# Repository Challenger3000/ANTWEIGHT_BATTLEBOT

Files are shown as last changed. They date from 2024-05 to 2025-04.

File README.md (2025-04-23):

"# ANTWEIGHT_ESP_BATTLEBOT" 

This is an example code that is meant to run an ESP32S3 battlebot / remote 

The main brain of the robot has the following hardware
1. ESP32S3
2. DRV8908 brushed motor driver IC
3. 3.3v regulator
4. 5.0v regulator
5. LSM6DSLTR Gyro/accelerometer
6. RGB LED
7. 1-4s battery charger

Transmitter hardware consists of 
1. ESP32S3
3. 3.3v regulator
5. LSM6DSLTR Gyro/accelerometer
6. 4x individually addressable RGB LEDs
7. 1-4s battery charger

The main features of this code ...
1. Conveneinent binding between robot and transmitter
2. Simple interface with the motor driver
3. 2x servo outputs on pins IO37 and IO38
4. PID control loop for yaw rate control
5. Website hosting over wifi for PID/Configuration setting changes.
6. Robot battery telemetry ais ccessible on the remote.

**Code uploading...**
1. install Arduino IDE 2.3.2 from https://www.arduino.cc/en/software
2. add "Arduino ESP32 Boards By Arduino" and "esp32 by Espressif v2.0.16" following this tutorial:
https://randomnerdtutorials.com/installing-the-esp32-board-in-arduino-ide-windows-instructions/

IMPORTANT!!!

To successfully compile code, make sure Esp32 library version is: 2.0.16

Otherwise the code does not compile.

image description

4. Try to compile, flash/verify, and install all libraries.
   * AsyncTCP
   * ESPAsyncWebServer
   * FastLED
   * FastIMU
   * 1euroFilter
   * PID
   * ESP32Servo   
5. Connect robot, select com port and chose ESP32S3 Dev
6. Set these parameters in arduino ide:

image description

7. Upload code....
If you encounter exit status 1 or status 2, or the IDE claims the controller does not respond...
This means that the BootLoader has been corrupted. Usually caused by flashing Firmware with ERASER ALL FLASH enabled.
To fix this...
1. Hold down PROGRAM button found on the back side of the main board while powering on.
2. Select Esptool as the programmer in the tools dropdown menu,
3. Click BurnBootloader button within tools doropdown menu (takes about 15-20s to complete)
4. After you see "Hard reset" message in the console, upload the code again.
After upload perform a reboot, and you should be able to upload the code without heaving to press the PROGRAM button every time

**Binding process...**

1. Hold down "B" button on transmitter and turn it on, once you see the second rgb led from the left side blinking blue and cyan.
2. Hold top side button on the robot while turning the robot on until you see rgb led blinking blue and cyan.
3. Keep the robots withing 2m or so, it should take around 5 seconds to bind.
   
**Motor driver...**

The motor driver onboard has 4 full bridges. So its capable of driving 4 1.0 - 1.5 A motors, or 2 2.0 - 3.0 A motors
You have to chose the descired configuration in configuration.h by setting 
MOTOR_LAYOUT = PARALEL_AC_BD or INDIVIDUAL_A_B_C_D
After initializing the motor driver, you can simply use drive_motor_A() and motor A will drive.
If you're using 2 parallel motors and not 4 individual motors, motor A C, and B D, will work together to achieve more current.
For more detailed information for the motor driver, you can check out the datasheet: 
https://www.ti.com/lit/ds/symlink/drv8912-q1.pdf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
The motor driver has OVER CURRENT PROTECTION, if robot detects the over current protection it will flash onboard status led YELOW.

**PID control...**

The robot and remote has a built-in imu in both robot and transmitter. Currently not supported on transmitters side. IMU used is LSM6DSLTR, SDA is connected to io48 and SCL to io47, in case you want to add support.
By default, robot comes with, 3 modes on 2nd switch. Off on the bottom, On no IMU in the middle, On with imu stabilisation pointing forwards.
When in imu stabilisation mode, robot will track rotational speed.
For example if the sitck is in the middle, the robot will try to stay motionless, it will resist pushes and hit better.
If you rotate your stick as far to the left as you can, it will by default try to maintain 600 deg/s. This can be changed in configuration.h.

**Website hosting over wifi...**

For imu PIDs to work you need to tune them. the easiest way to do that is by using wifi website mode. 
To aces this website press the general purpose button while the robot is on, led will change to purple and control will be lost.
Then you can connect to wifi, by default its called PID_SETUP_WIFI with pasword 12345678 . PLEASE CHANGE THIS TO YOUR OWN WIFI NAME AND PASS.
Then connect to wifi and open this: 192.168.4.1 IP address in a browser. You will be greated with a website asking for P I and D parameters
After your done changing pids, you click send, if the robot receives the changes, it will flash white once. then you can click the button again to go back to driving mode.
The website being hosted can be changed, in wifi.ino file.

**Robot led status explanations...**

Red - not connected,
Red blinking - Calibrating IMU
Green - connected, 
Yellow - motor driver over current

Robot board consists of main brain with the driver, and imu. and an addon charger board. 
REMEBER TO SHORT THE CORRECT SOLDER BRIDGE CORSPONDING TO YOUR BATTERY!
(Default is 3s)

image description
image description
image description
image description

**Transmitter has 4 addressable LEDs...**

* 1st LED ... green - yellow - red - red blinking - black.... the color state represents the charge state of the remote.
* 2nd LED ...
  * green - yellow - red - red blinking - black.... all of them represent the charge state of the robot. (only if telemetry from robot is present)
  * Blue/cyan blinking - binding mod.
* 3rd LED joystick X-axis calibration indicator
* 4rd LED joystick Y-axis calibration indicator

**Transmitter joystick calibration**
3rd and 4th LEDs help identify a bad joystick calibration.
Both LEDs represent joystick data after applying limit and midpoint calibration.
3rd LED - x-axis, 4th LED - y axis.
  * green - axis centered,
  * yellow - axis is moved off center,
  * red - axis at the limit of travel.

If you dont see a green indicator on 3rd and 4th LED while stick is in the middle,
this means that the stick is not calibrated correctly.
To calibrate the youstick,
  1. Pull the stick to the left bottom corner while powering on the remote.
  2. Release the stick once you see RED - GREEN blinking indicators on ALL LEDs.
     (while the LEDs indicate a solid RED color, its calibrating the midpoint of the joystick, so do not move it)
  3. When all 4 leds indicate a YELLOW light, move the stick around to all corners and edges.
     (this stage lasts for 10s, I usually just rotate it clockwise and counterclockwise for 3 times each.)
  4. When you see a green light, the calibration is finishes and parameters saved.

**Keep in mind!**

Esp32 s3 doesn't like Printing in serial while no serial connection is present, so comment out all serial print or use switches on the transmitter to enable/disable serial prints on the robot/transmitter.
If you do a lot of printing, with no serial cable attached, ESP will start to lag

While connecting the usb extension board, make sure d+ and d- are connected accordingly.

**Hardware revision changelog**
Revision v2.0 remote VS v2.1:

image description

Diffrence: A/B push buttons swapped, NEW more durrable power switch.

Revision v2.0 brain board VS v2.1:

image description

Diffrence: Added extra VSENSE pin for higher voltage weapon battery (drive batery VSENSE moved to pin 9 from 10. New extra VSENSE pin 10)

**TODO**
1. Need to organize and clean transmitter code.
2. Update the code to work with the newer version of ESP32 and FastLED librarys...
3. Switch to a newer/better/from scratch IMU/PID library, cause the current ones stop working after "micros()" overflows.
4. Add support for brushels esc drive.

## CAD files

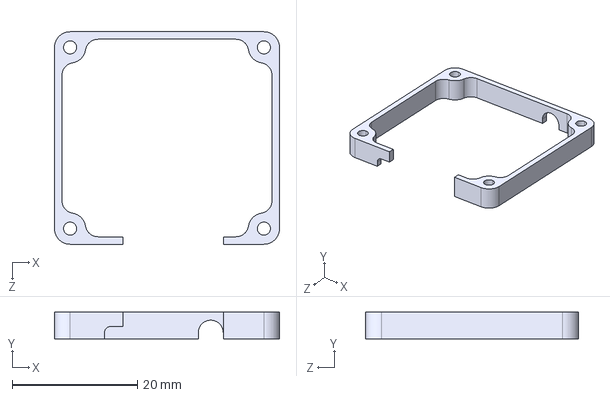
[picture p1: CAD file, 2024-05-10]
3D_files/BrainSpacer.STEP
36.0 x 4.30 x 34.0 mm

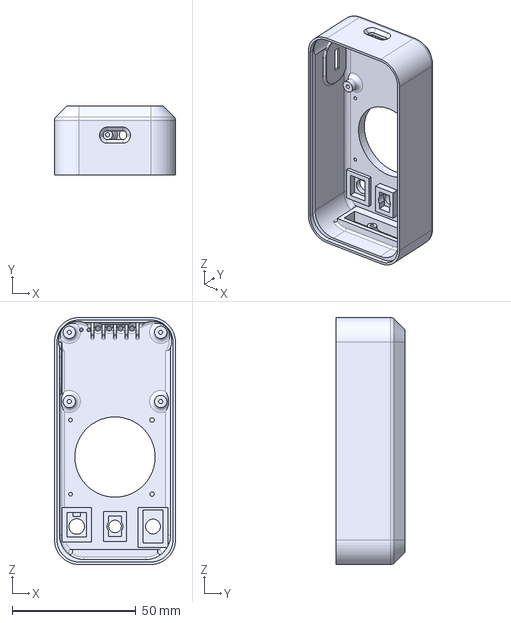
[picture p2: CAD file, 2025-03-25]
3D_files/NuleTX REV 2/NULE TX v3.3.step
49.0 x 28.0 x 100.0 mm

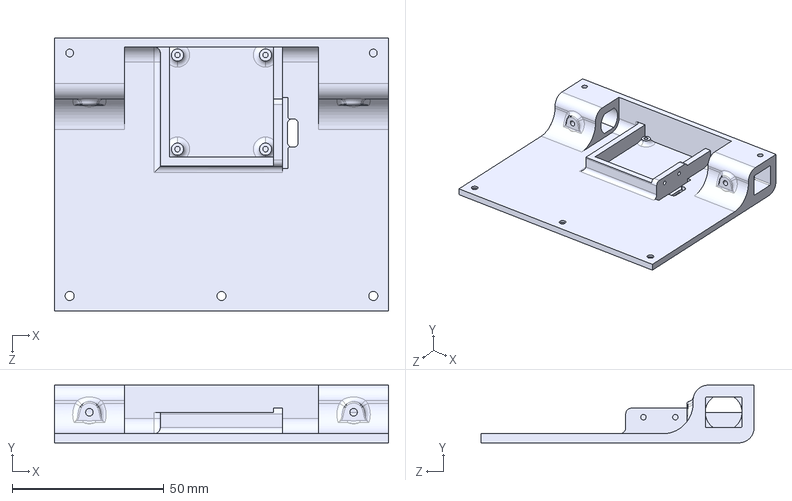
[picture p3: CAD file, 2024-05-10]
3D_files/BasicDriveNule.STEP
110.0 x 19.0 x 90.0 mm

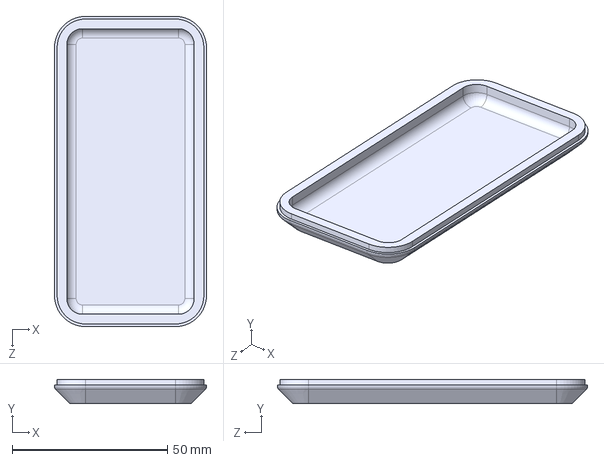
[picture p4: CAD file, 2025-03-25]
3D_files/NuleTX REV 2/NULE TX LID.step
49.0 x 7.80 x 100.0 mm

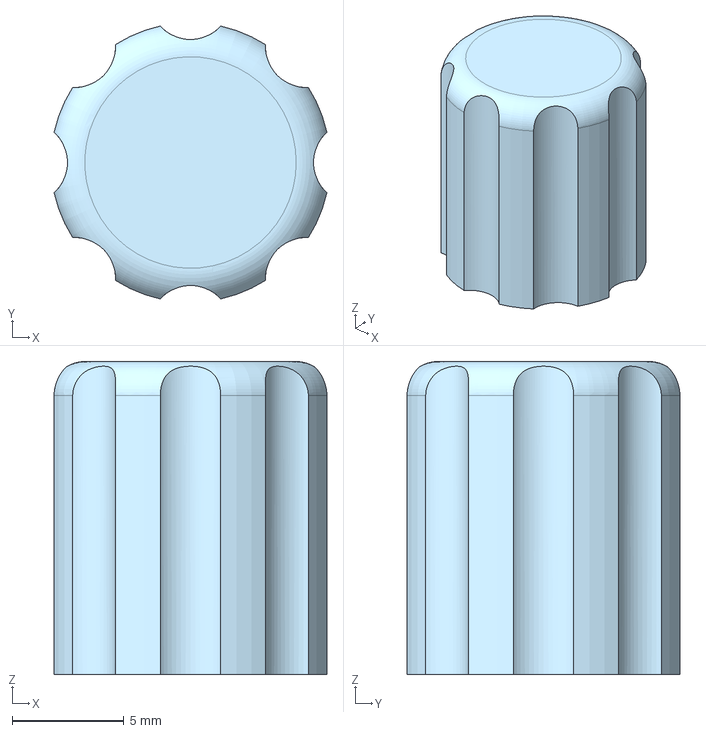
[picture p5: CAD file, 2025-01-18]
3D_files/NuleTX REV 2/Knob.step
12.2 x 12.2 x 14.0 mm

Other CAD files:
3D_files/NuleTX REV 1/NuleTXLid.STEP
3D_files/NuleTX REV 1/NuleTX_v1.0.STEP
3D_files/NuleTX REV 1/NuleTX_v1.1.step

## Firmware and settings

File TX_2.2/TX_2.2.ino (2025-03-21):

// general
enum TX_STATES {
  IDLE,
  SENDING,
  BINDING,
};
uint8_t state = SENDING;
bool new_rx_data = false;

// eeprom code start
#define EEPROM_SIZE 200
#define EEPROM_ADDRES 100
#include <EEPROM.h>

typedef struct struct_eeprom {
  uint8_t   eeprom_structure_version;
  uint8_t   reserved;
  uint8_t   need_to_calibrate;
  int32_t   calib_x_low;
  int32_t   calib_x_high;
  int32_t   calib_y_low;
  int32_t   calib_y_high;
  int32_t   offset_x;
  int32_t   offset_y;
  uint8_t   binding_status;
  uint8_t   bound_ch;
  uint8_t   bound_mac[6];
  char      encryption_key[16];
} struct_eeprom;
struct_eeprom EEPROM_DATA;

void init_eeprom(){  
  EEPROM.begin(EEPROM_SIZE);
  EEPROM.get(EEPROM_ADDRES, EEPROM_DATA);
}
// eeprom code end

// esp now code start
#include "esp_wifi.h"
#include <esp_now.h>
#include <WiFi.h>
void OnDataSent(const uint8_t *mac_addr, esp_now_send_status_t status);
#define rssi_list_size 50
#define binding_ch 14
uint8_t current_ch = 0;
uint8_t sending_ch = 5;
uint8_t broadcastAddress[] = {0xFF, 0xFF, 0xFF, 0xFF, 0xFF, 0xFF};
char pmk_key_str[16];
uint16_t failed_packet_count = 0;
bool rx_lost = true;

struct rssi_data {
  uint8_t mac_address[6];
  int rssi;
  uint8_t received_packets;
};
rssi_data rssi_list[rssi_list_size] = {0};
rssi_data rssi_receive_buffer[rssi_list_size] = {0};
uint8_t rssi_list_index = 0;
uint8_t rssi_receive_buffer_index = 0;
uint8_t strongest_rssi_index = 0;

unsigned long last_strongest_receive = 0;
unsigned long last_sendtime = 0;
unsigned long last_receive=0;
esp_now_peer_info_t peerInfo;
// esp now code end

// hardware pins
#define g_x 4
#define g_y 5
#define pot 6
#define switch_1      14
#define switch_2_up   12
#define switch_2_down 11
#define switch_3      13
#define vbat 8

// rev 2.0
// #define BTN_A 9
// #define BTN_B 21

// rev 2.1
#define BTN_A 21
#define BTN_B 9

// variables
typedef struct struct_message_rx {
  float     volatage;
} struct_message_rx;
struct_message_rx rxData;

typedef struct struct_message_tx {
  uint8_t   mode;
  uint8_t   id;
  int32_t   x_axis;
  int32_t   y_axis;
  uint32_t  pot_1;
  uint8_t   sw_1;
  uint8_t   sw_2;
  uint8_t   sw_3;
  uint8_t   btn_A;
  uint8_t   btn_B;
  uint8_t   ch09;
  uint8_t   ch10;
  uint8_t   ch11;
  uint8_t   ch12;
  uint8_t   ch13;
  uint8_t   ch14;
  uint8_t   ch15;
  uint8_t   ch16;
  char string[16];
  uint8_t mac[6];
} struct_message_tx;
struct_message_tx txData;
int ch1_offset = 0;
int ch2_offset = 0;
int motorA = 0;
int motorB = 0;
uint8_t expo_B = 0;


// led code start
#include <FastLED.h>
#define NUM_LEDS 4
#define DATA_PIN 1
CRGB leds[NUM_LEDS];
unsigned long last_led_update = 0;
bool led_warning_phase = false;
// led code end

// rssi
typedef struct {
  unsigned frame_ctrl: 16;
  unsigned duration_id: 16;
  uint8_t addr1[6]; /* receiver address */
  uint8_t addr2[6]; /* sender address */
  uint8_t addr3[6]; /* filtering address */
  unsigned sequence_ctrl: 16;
  uint8_t addr4[6]; /* optional */
} wifi_ieee80211_mac_hdr_t;

typedef struct {
  wifi_ieee80211_mac_hdr_t hdr;
  uint8_t payload[0]; /* network data ended with 4 bytes csum (CRC32) */
} wifi_ieee80211_packet_t;

int rssi_last;
unsigned long last_list_print = 0;

void setup() {
  // Serial.begin(115200);
  init_led();
  init_eeprom();
  init_gpio();

  if (get_button_B()) {
    state = BINDING;
  } else {
    if (EEPROM_DATA.binding_status == 1) {
      state = SENDING;
    } else {
      state = BINDING;
    }
  }

  init_data_structures();
  init_esp_now();
  init_joystick();
}

void loop() {
  if(millis()-last_led_update > 25){
    last_led_update = millis();
    update_leds();

    // print all hardware pin values
    
    // Serial.print("x: ");
    // Serial.print(mapWithMidpoint(constrain(analogRead(g_x),EEPROM_DATA.calib_x_low ,EEPROM_DATA.calib_x_high), EEPROM_DATA.calib_x_low, ch1_offset, EEPROM_DATA.calib_x_high, 0, 4095));
    // Serial.print("\ty: ");
    // Serial.print(mapWithMidpoint(constrain(analogRead(g_y),EEPROM_DATA.calib_y_low,EEPROM_DATA.calib_y_high), EEPROM_DATA.calib_y_low, ch2_offset, EEPROM_DATA.calib_y_high, 0, 4095));
    // Serial.print("g_x: ");
    // Serial.print(analogRead(g_x));
    // Serial.print("\tg_y: ");
    // Serial.print(analogRead(g_y));
    // Serial.print("\tpot: ");
    // Serial.print(analogRead(pot));
    // Serial.print("\tsw1: ");
    // Serial.print(get_switch_1());
    // Serial.print("\tsw2: ");
    // Serial.print(get_switch_2());
    // Serial.print("\tsw3: ");
    // Serial.print(get_switch_3());
    // Serial.print("\tBTN_A: ");
    // Serial.print(get_button_A());
    // Serial.print("\tBTN_B: ");
    // Serial.println(get_button_B());
  }

  switch (state) {
    case SENDING:

      if(!rx_lost && millis()-last_sendtime > 50){
        last_sendtime = millis();
        send_data();
      }else if(rx_lost && millis()-last_sendtime > 1000){
        last_sendtime = millis();
        send_data();
      }
      break;

    case BINDING:      
      binding();
      break;
  }
}

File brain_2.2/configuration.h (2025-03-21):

// Drive motor related settings
bool motors_on = true;                      // turns on and off all motors in one boolean. 
#define max_throttle 255                    // max throttle value  
// INDIVIDUAL_A_B_C_D - for 1x4 individual motors.
// PARALEL_AC_BD      - for 2x2 motors with A C outputs and B D outputs being paralel.
uint8_t MOTOR_LAYOUT = PARALEL_AC_BD;       // selects motor layout betwheen 2 paralel, and 4 individual
float battery_critical_v = 3.0;
#define cell_count 2.0;

// servo
int servo_1_init_position = 0;              // initial servo position
int servo_2_init_position = 0;              // initial servo position

int servo_1_failsave_position = 0;          // initial servo position
int servo_2_failsave_position = 0;          // initial servo position

bool arming_throttle_protection = true;     // prevents esc from spinning if armed with above 0 throttle

// Wifi related settings
const char* ssid = "PID_SETUP_WIFI";
const char* password = "12345678";

// imu settings
bool use_imu_for_yaw_rate = true;           // if true, yaw rate will be adjusted from imu yaw rate
#define max_yaw_rate 600                    // max yaw rate in degrees per second

// failsave
unsigned int failsave_delay = 500;          // ms until failsave is activated.
#define WDT_TIMEOUT 1                       // watchdog timeout (1s)

// hardware pins
#define SERVO_1_PIN 38
#define SERVO_2_PIN 37
#define BUTTON 4

// rev 2.0
// #define VSENSE 10

// rev v2.1
#define VSENSE 9
// #define VSENSE 10 // changed on rev_2.1 brain boards. can be used to detect voltage of extra external battery

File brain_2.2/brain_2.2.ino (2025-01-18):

#include "variables.h"
#include "configuration.h"

#include <esp_task_wdt.h>

void setup() {
  // Serial.begin(115200);
  init_gpio();
  init_eeprom();
  init_led();
  init_esp_now_rx();
  init_pid();
  init_servo();
  init_imu();
  init_filter();
  init_drv8908(MOTOR_LAYOUT);
  init_watchdog();
}

void loop() {
  led_update();                   // updates the led color based current status
  update_gpio();                  // reads the button and sends the voltage telemetry
  update_filter();                // filters imu data
  update_pid();                   // calculates the PID output
  driving_logic();                // mixes received data and sends it to the motor driver
}

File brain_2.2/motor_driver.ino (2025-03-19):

uint8_t write_register_drv8908(uint8_t write_register, uint8_t write_data){
  digitalWrite(CHIP_SEL, LOW);
  SPI.beginTransaction(SPISettings(1000000, MSBFIRST, SPI_MODE1));
  delayMicroseconds(1);
  drv8908_status = SPI.transfer(write_register);
  uint8_t received_data = SPI.transfer(write_data);
  SPI.endTransaction();
  delayMicroseconds(1);
  digitalWrite(CHIP_SEL, HIGH);
  delayMicroseconds(1);
  // delay(1);
  return received_data;
}

uint8_t read_register_drv8908(uint8_t read_register){
  digitalWrite(CHIP_SEL, LOW);
  SPI.beginTransaction(SPISettings(1000000, MSBFIRST, SPI_MODE1));
  delayMicroseconds(1);
  drv8908_status = SPI.transfer(0b01000000 | read_register);
  uint8_t received_data = SPI.transfer(0x00);
  SPI.endTransaction();
  delayMicroseconds(1);  
  digitalWrite(CHIP_SEL, HIGH);
  delayMicroseconds(1);
  // delay(1);
  return received_data;
}

uint8_t prepare_motor_register(uint8_t motor, uint8_t register){
  uint8_t motor_register = 0;

  return motor_register;
}

void drive_motor_A(uint8_t new_state, uint8_t PWM){
  switch (MOTOR_LAYOUT) {
    case PARALEL_AC_BD:
      switch (new_state) {
        case FORWARD:
          MOTOR_A1_STATE = A1_FORWARD;
          MOTOR_A2_STATE = A2_FORWARD;
          MOTOR_C1_STATE = C1_FORWARD;
          MOTOR_C2_STATE = C2_FORWARD;
          break;
        case BACKWARD:
          MOTOR_A1_STATE = A1_BACKWARD;
          MOTOR_A2_STATE = A2_BACKWARD;
          MOTOR_C1_STATE = C1_BACKWARD;
          MOTOR_C2_STATE = C2_BACKWARD;
          break;
        case COAST: 
          MOTOR_A1_STATE = A1_COAST;
          MOTOR_A2_STATE = A2_COAST;
          MOTOR_C1_STATE = C1_COAST;
          MOTOR_C2_STATE = C2_COAST;
          break;
        case BREAK:
          MOTOR_A1_STATE = A1_BREAK;
          MOTOR_A2_STATE = A2_BREAK;
          MOTOR_C1_STATE = C1_BREAK;
          MOTOR_C2_STATE = C2_BREAK;
          break;
      }
            
      // write_register_drv8908(PWM_CTRL_2, 0xFF);  // disable pwm generation
      write_register_drv8908(PWM_DUTY_1, 0);
      write_register_drv8908(OP_CTRL_1, MOTOR_A1_STATE | MOTOR_B1_STATE | MOTOR_C1_STATE | MOTOR_D1_STATE);
      write_register_drv8908(OP_CTRL_2, MOTOR_A2_STATE | MOTOR_B2_STATE | MOTOR_C2_STATE | MOTOR_D2_STATE);

      // Serial.print("OCP STATUS: ");
      // Serial.print(read_register_drv8908(OCP_STAT_1), BIN);
      // Serial.print(" : ");
      // Serial.println(read_register_drv8908(OCP_STAT_2), BIN);

      if(motors_on){
        write_register_drv8908(PWM_DUTY_1, constrain(PWM,0,max_throttle));
      }else{
        write_register_drv8908(PWM_DUTY_1, 0);
      }
      // write_register_drv8908(PWM_CTRL_2, 0x00);  // enable pwm generation
      break;
    case INDIVIDUAL_A_B_C_D:
      switch (new_state) {
        case FORWARD:
          MOTOR_A1_STATE = A1_FORWARD;
          MOTOR_A2_STATE = A2_FORWARD;
          break;
        case BACKWARD:
          MOTOR_A1_STATE = A1_BACKWARD;
          MOTOR_A2_STATE = A2_BACKWARD;
          break;
        case COAST: 
          MOTOR_A1_STATE = A1_COAST;
          MOTOR_A2_STATE = A2_COAST;
          break;
        case BREAK:
          MOTOR_A1_STATE = A1_BREAK;
          MOTOR_A2_STATE = A2_BREAK;
          break;
      }
            
      // write_register_drv8908(PWM_CTRL_2, 0xFF);  // disable pwm generation
      // write_register_drv8908(PWM_DUTY_1, 0);
      write_register_drv8908(OP_CTRL_1, MOTOR_A1_STATE | MOTOR_B1_STATE | MOTOR_C1_STATE | MOTOR_D1_STATE);
      write_register_drv8908(OP_CTRL_2, MOTOR_A2_STATE | MOTOR_B2_STATE | MOTOR_C2_STATE | MOTOR_D2_STATE);

      // Serial.print("OCP STATUS: ");
      // Serial.print(read_register_drv8908(OCP_STAT_1), BIN);
      // Serial.print(" : ");
      // Serial.println(read_register_drv8908(OCP_STAT_2), BIN);

      if(motors_on){
        write_register_drv8908(PWM_DUTY_1, constrain(PWM,0,max_throttle));
      }else{
        write_register_drv8908(PWM_DUTY_1, 0);
      }
      // write_register_drv8908(PWM_CTRL_2, 0x00);  // enable pwm generation
      break;
  }
}

void drive_motor_B(uint8_t new_state, uint8_t PWM){
  switch (MOTOR_LAYOUT) {
    case PARALEL_AC_BD:
      switch (new_state) {
        case FORWARD:
          MOTOR_B1_STATE = B1_FORWARD;
          MOTOR_B2_STATE = B2_FORWARD;
          MOTOR_D1_STATE = D1_FORWARD;
          MOTOR_D2_STATE = D2_FORWARD;
          break;
        case BACKWARD:
          MOTOR_B1_STATE = B1_BACKWARD;
          MOTOR_B2_STATE = B2_BACKWARD;
          MOTOR_D1_STATE = D1_BACKWARD;
          MOTOR_D2_STATE = D2_BACKWARD;
          break;
        case COAST: 
          MOTOR_B1_STATE = B1_COAST;
          MOTOR_B2_STATE = B2_COAST;
          MOTOR_D1_STATE = D1_COAST;
          MOTOR_D2_STATE = D2_COAST;
          break;
        case BREAK:
          MOTOR_B1_STATE = B1_BREAK;
          MOTOR_B2_STATE = B2_BREAK;
          MOTOR_D1_STATE = D1_BREAK;
          MOTOR_D2_STATE = D2_BREAK;
          break;
      }
      // write_register_drv8908(PWM_CTRL_2, 0xFF);  // disable pwm generation
      write_register_drv8908(PWM_DUTY_2, 0);
      write_register_drv8908(OP_CTRL_1, MOTOR_A1_STATE | MOTOR_B1_STATE | MOTOR_C1_STATE | MOTOR_D1_STATE);
      write_register_drv8908(OP_CTRL_2, MOTOR_A2_STATE | MOTOR_B2_STATE | MOTOR_C2_STATE | MOTOR_D2_STATE);
      if(motors_on){
        write_register_drv8908(PWM_DUTY_2, constrain(PWM,0,max_throttle));  // sets motor duty cycle
      }else{
        write_register_drv8908(PWM_DUTY_2, 0);
      }
      // write_register_drv8908(PWM_CTRL_2, 0x00);  // enable pwm generation
      break;
    case INDIVIDUAL_A_B_C_D:
      switch (new_state) {
        case FORWARD:
          MOTOR_B1_STATE = B1_FORWARD;
          MOTOR_B2_STATE = B2_FORWARD;
          break;
        case BACKWARD:
          MOTOR_B1_STATE = B1_BACKWARD;
          MOTOR_B2_STATE = B2_BACKWARD;
          break;
        case COAST: 
          MOTOR_B1_STATE = B1_COAST;
          MOTOR_B2_STATE = B2_COAST;
          break;
        case BREAK:
          MOTOR_B1_STATE = B1_BREAK;
          MOTOR_B2_STATE = B2_BREAK;
          break;
      }
            
      // write_register_drv8908(PWM_CTRL_2, 0xFF);  // disable pwm generation
      write_register_drv8908(OP_CTRL_1, MOTOR_A1_STATE | MOTOR_B1_STATE | MOTOR_C1_STATE | MOTOR_D1_STATE);
      write_register_drv8908(OP_CTRL_2, MOTOR_A2_STATE | MOTOR_B2_STATE | MOTOR_C2_STATE | MOTOR_D2_STATE);

      // Serial.print("OCP STATUS: ");
      // Serial.print(read_register_drv8908(OCP_STAT_1), BIN);
      // Serial.print(" : ");
      // Serial.println(read_register_drv8908(OCP_STAT_2), BIN);

      if(motors_on){
        write_register_drv8908(PWM_DUTY_2, constrain(PWM,0,max_throttle));
      }else{
        write_register_drv8908(PWM_DUTY_2, 0);
      }
      // write_register_drv8908(PWM_CTRL_2, 0x00);  // enable pwm generation
      break;
  }
}
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

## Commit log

2024-01-26 servo + motors work
2024-01-26 EEPROM + SERVO + MOTORS WORK
2024-01-26 driving ok, needs servo
2024-02-24 added esp32 analog remote
2024-02-25 manual big joystick calibration
2024-03-15 pwm test working succesful
2024-03-16 motor driver done
2024-03-16 added mixer, calibration, expo
2024-03-16 added pid :D
2024-03-17 added rgb led support
2024-03-17 added wifi pid tuning website
2024-03-23 eeprom calibration value save for joystick
2024-04-08 3x more power
2024-04-16 no luck with charger
2024-04-17 working 2s charging ig?
2024-05-02 fixing one wheel overcurrent bug
2024-05-03 fixed motor issue
2024-05-04 4 motor support ?
    [configuration.h]
2024-05-05 4 motor support done, led status done.
    [configuration.h]
2024-05-06 progress save
    [configuration.h]
2024-05-08 mental progress
    [configuration.h]
2024-05-09 almost final update
    [configuration.h]
2024-05-10 fixed calibration
2024-05-10 cleaning up
    [configuration.h]
2024-05-10 Update motor_driver.ino
    less overcurrent error
    [motor_driver.ino]
2024-05-10 Update motor_driver.ino
    fixed typo
    [motor_driver.ino]
2024-05-10 Add files via upload
    added 3d models
    [BasicDriveNule.STEP, BrainSpacer.STEP, NuleTX.STEP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]
2024-05-17 fixed corrupted packets, fixed failsaves,
    [configuration.h]
2024-05-18 added HW watchdog, to prevent runaway
    [configuration.h]
2024-05-18 fixed driving up side down, with pids
    [motor_driver.ino]
2024-05-18 fixed driving up side down
    [motor_driver.ino]
2024-05-18 changed file names
    [configuration.h]
2024-05-18 changed incorret genneral purpouse button pin
    [configuration.h]
2024-11-16 Update README.md
    Specified the required Esp32 version
2025-01-15 Fixed booting cleared memory
    [esp_now.ino]
2025-01-18 Added proper joystick calibration indicators, Added joystick re-calibration mode, Added joystick end point indicators on 3rd and 4th leds, Added forced robot reboot if pid/imu libs overflow, Adjusted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
    [TX_2.2.ino, brain_2.2.ino, esp_now.ino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]
2025-01-18 Added joystick center indicator, Added potentiometer knob step file.
    [Knob.step]
2025-01-23 added a slightly modified 3d body for the remote.
    [NuleTX.STEP, NuleTX_v1.0.STEP, NuleTX_v1.1.step]
2025-03-19 slight quality of life update.
    [configuration.h]
2025-03-21 fixed an incorrect pin definition for v2.1 boards
    [configuration.h]
2025-03-21 fixed VSENSE pin definition for v2.1 boards.
    [configuration.h]
2025-03-21 Fixed VSENSE pin definitions for v2.1 boards
    [TX_2.2.ino]
2025-03-25 Added revision 2 3d body model
    [Knob.step, NULE TX LID.step, NULE TX v3.3.step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]
